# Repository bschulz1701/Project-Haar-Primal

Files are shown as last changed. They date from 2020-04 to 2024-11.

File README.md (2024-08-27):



# Project-Haar-Primal
A minimal temp/pressure/RH sensor designed for environmental monitoring. Built off the [Haar](https://github.com/NorthernWidget-Skunkworks/Project-Haar) system, developed by Bobby Schulz at Northern Widget 

# Repo Roadmap
#### [Documents](Documents/) 

General document and image storage for repo and README

#### [Hardware](Hardware/)

Current board files (Eagle), Bill of Materials (BoM), and other design documents

#### [Production](Production/)

Contains the various Gerber and pick and place files required to have the Printed Circuit Boards (PCBs) manufactured or populated 

#### [Software](Software/)

The software associated with the piece of hardware, this is usually diagnostic software used for verifying or investigating the hardware

#### [Mechanical](Mechanical/)

Mechanical design files and assembly documents

<!-- #### [Testing](Testing/)

Scripts and results from the testing process and development process. Contains more detailed information about documented issues among other testing. 
 -->

## Overview
* **Type:** Sensor
* **Interfaces:** I<sup>2</sup>C
* **Release Version:** v2.0 - 2022/03/17

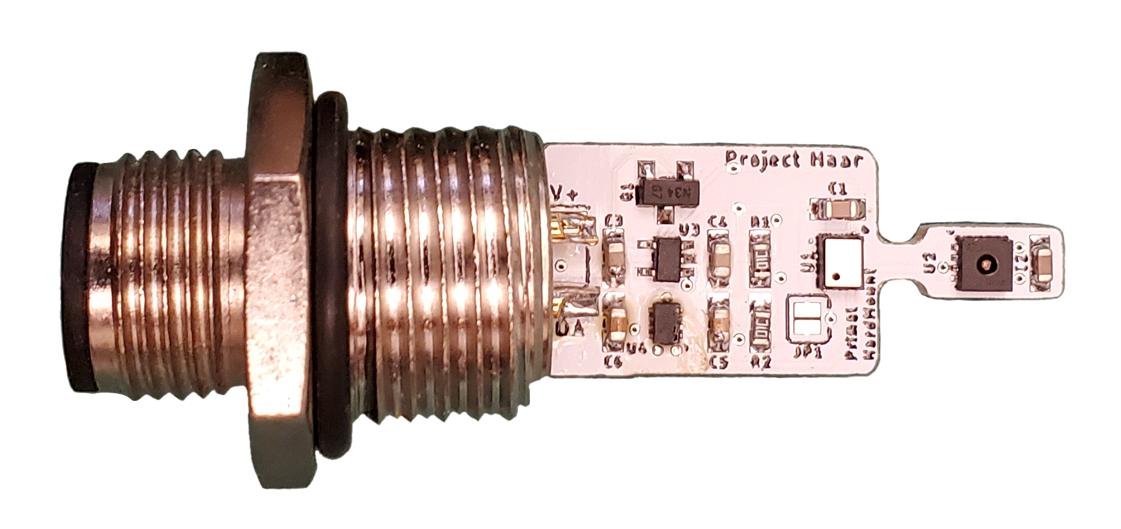
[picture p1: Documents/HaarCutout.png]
Haar Board Cutout


<!-- ![Haar v0.0 - Bottom](Documents/Images/Haar_0v0_Bottom_Cropped.jpg) -->

## Features
### On-Board
* Selectable Pullups
* Reverse Polarity Protection  

### Interface
* I<sup>2</sup>C
* M12 circular connector 

<picture>
  <source media="(prefers-color-scheme: dark)" srcset="Documents/Pinout_LIGHT.png">
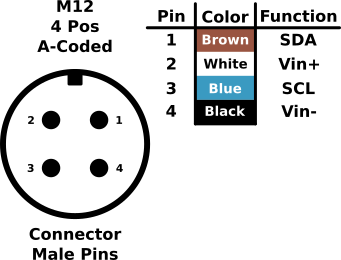
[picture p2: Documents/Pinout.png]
Haar Connector Pinout
  
</picture>

## Specifications
* **Voltage - Supply:** 3.3V
* **Voltage - Logic:** 3.3V
* **Input Current (Avg, 1s period): 30.95&mu;A @ 3.3V**
* **Input Current (Avg, 5s period): 107.43&mu;A @ 3.3V**
* **Input Current (Max): 0.45mA @ 3.3V**

#### Sensor
**Temperature** [^1]
* Range: -40 ~ 125°C 
* Accuracy: &plusmn; 0.2°C
* Repeatability: &plusmn; 0.04°C

**Pressure** [^2]
* Range: 300 ~ 1200 hPa  
* Accuracy: &plusmn; 1 hPa
* Repeatability: &plusmn; 0.06 hPa

**Humidity** [^1]
* Range: 0 ~ 100%
* Accuracy: &plusmn; 2%
* Repeatability: 0.08%

[^1]: [SHT31 Datasheet](https://sensirion.com/media/documents/213E6A3B/63A5A569/Datasheet_SHT3x_DIS.pdf)
[^2]: [DPS368 Datasheet](https://www.infineon.com/dgdl/Infineon-DPS368-DS-v01_00-EN.pdf?fileId=5546d46269e1c019016a0c45105d4b40)

## Version History

`v0.0` - Initial primal version with screw terminal

`v0.1` - Initial 'hard mount' version, using M12 connector

`v1.0` - Removed pullup select[^3], added logic level buffer and voltage reg on input

`v1.1` - Moved via away from connector pads to prevent bridging when soldering 

`v2.0` - Fixed issue with address select jumper[^3]

## Jumper Settings 

> [!IMPORTANT]
> Jumper settings valid for version `v2.0` and beyond[^3]

[^3]: See Errata

**Configuration Jumpers**
| Jumper | Purpose | Open | Closed | Default | 
| --- | --- | --- | --- | ----- |
| `JP1` | I<sup>2</sup>C Address Select | Base Address<sup>&dagger;</sup> | Alt Address<sup>&Dagger;</sup> | Open |

&dagger; SHT31 = `0x44`, DPS368 = `0x76`

&Dagger; SHT31 = `0x44`, DPS368 = `0x77`

## Known Issues/Errata

#### Solder Jumper Stencil

**Version Affected:** All

**Issue:** Depending on the thickness of the solder stencil used for populating the board, the solder jumpers may not bridge when desired. This is due to lack of stencil thickness specification and pad geometry.

**Workaround:** Make a note on the board assembly (if working with a board house) as to which jumpers should be connected (see jumper tables). Otherwise, if assembling manually, check the jumpers are connected, and bridge them using solder wire and a soldering iron if they have failed to jump where desired. 

#### Pullup Jumper

**Version Affected:** `v0.0`

**Issue:** Due to the resistor configuration with the solder jumper, if the jumper is left open, the resistors form a voltage divider which pulls down the I<sup>2</sup>C rails and causes a variety of bus failures.

**Workaround:** Leave jumper closed on device, this will pull the lines up to the 3.3V rail and prevent the issue 

**Resolution:** Fixed in version `v0.1` and beyond  

#### Address Jumper

**Version Affected:** `v0.1` to `v1.1`

**Issue:** `SDO` pin on DSP368 was erroniously left floating, meaning the DPS368 is continually fixed at the address of `0x76` and will not be effected by the address jumper status

**Workaround:** Leave jumper closed on device, this will hold the SHT31 at the default address as well and keep the address combination consistent 

**Resolution:** Fixed in version `v2.0` and beyond

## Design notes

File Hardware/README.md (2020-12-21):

# Hardware Overview - Project Hyena

## Files

<!-- * [Legacy](Legacy/) - File storage for older hardware versions   -->
* Haar_Primal.sch - Eagle Schematic
* Haar_Primal.brd - Eagle Board File
* [Haar_Primal_0v0_DimensionalDrawing.pdf](Haar_Primal_0v0_DimensionalDrawing.png) - Mechanical Drawing
<!-- * [PrimaryLogger_BoM.csv](PrimaryLogger_BoM.csv) - BoM (For reference only, see [Production](../Production) for production ready BoM) -->
<!-- * [PrimaryLogger.pdf](PrimaryLogger_0v2.pdf) - PDF of Schematic  -->

## I2C Addresses 

| Device | Address | 
| --- | --- |
| DPS368 | 0x77 | 
| SHT30 | 0x44 |

<!-- ## Pinout

| Particle Pin | Hyena Pin Name | Control | Function | 
| --- | --- | --- | --- |
| 8 | `3V3_EXT_EN` | Output | Enables the external 3.3v rail (active high, nominally low) | 
| 7 | `WD_HOLD` | Output | Controls the hardware watchdog timer, pulse high to "feed" timer |
| 6 | `GPIO1D` | IO | General digital IO pin for external sensors (J1 Connector) | 
| 5 | `GPIO2D` | IO | General digital IO pin for external sensors (J2 Connector) | 
| 4 | `GPIO3D` | IO | General digital IO pin for external sensors (J3 Connector) | 
| 3 | `RTC_INT` | Input | Interrupt line from RTC, natively high active low (open drain), triggers on falling edge |
| 2 | `SDA_CTRL` | Output | Used to turn internal I2C on or off (active high, I2C_OB on, natively low) |
| 1 | `SCL` | Output | I2C clock line |
| 0 | `SDA` | IO | I2C Data line |
| 9 | `3V3_SD_EN` | Output | Enable line for SD card 3.3v supply (active high, natively low) |
| 10 | `IO_EXP_INT` | Input | Global interrupt from the IO expander (functionality configurable via software) |
| 11 | `MISO` | Input | MasterInSlaveOut, part of SPI bus |
| 12 | `MOSI` | Output | MasterOutSlaveIn, part of SPI bus | 
| 13 | `SCK` | Output | SerialClocK, part of SPI bus | 
| 14 | `SD_CS` | Output | SD chip select line, active low |
| 15/ADC4 | `TIP` | IO | Designed as tipping bucket rain gauge input, connected to J6, pulled high by default |
| 16/ADC3 | `GPIOXA` | IO | Intended as analog input for potentiometric input (J5) |
| 17/ADC2 | `GPIO1A` | IO | General digital/analog IO pin for external sensors (J1 Connector) |
| 18/ADC1 | `GPIO2A` | IO | General digital/analog IO pin for external sensors (J2 Connector) |
| 19/ADC0 | `GPIO3A` | IO | General digital/analog IO pin for external sensors (J3 Connector) |

| IO Expander Pin | Hyena Pin Name | Control | Function |
| --- | --- | --- | --- |
| 0 | `3V3_EXT_FAULT` | Input | Monitor pin for external 3v3 rail, if over current trip, pin is pulled low, natively high |
| 1 | `3V3_SD_FAULT` | Input | Monitor pin for SD card 3v3 rail, if over current trip, pin is pulled low, natively high |
| 2 | `SD_CD` | Input | Card detect pin for SD card, natively high, pulled low to indicate physical presence of SD card | 
| 3 | `I2C_EXT_EN` | Output | Control line for external I2C buffer, natively high (on), can be pulled low to turn off the external I2C bus | 
| 4 | `PAR_INT` | Input | Event interrupt line from TCS3400 light sensor (used for PAR measurement), active low interrupt |

## Hardware Testing:
See Testing sub folder -->

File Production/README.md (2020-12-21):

# Production
This folder contains files used to have the hardware manufactured 

## Files

#### Version v0.0 - Release Version

* [Geber](Haar_Primal_2020-03-13_x274.zip)
<!-- * [Top Mount](PrimaryLogger_v2.mnt) -->
* [BoM](Haar_Primal_0v0_BoM.csv)

### File Conventions 
* `HardwareName.mnb` - These are mount files (pick and place) for the bottom of the board
* `HardwareName.mnt` - These are mount files (pick and place) for the top of the board
* `HardwareName_YYYY-MM-DD_x274.zip` - These are Gerber (PCB) files from a given date in x274 format, which is accepted by most board houses

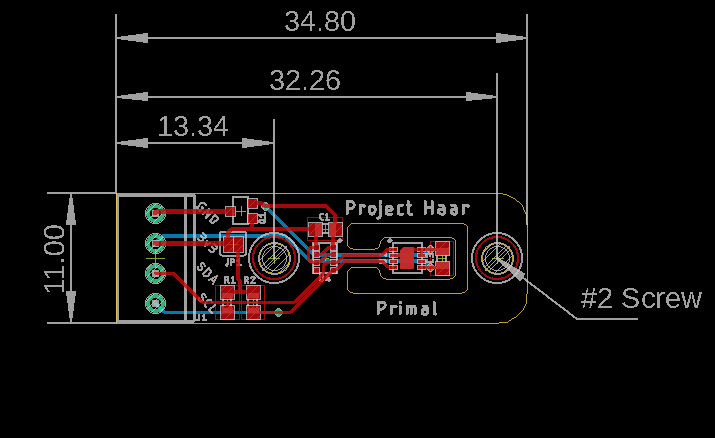
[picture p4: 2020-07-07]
Documents/Haar_Primal_0v0_DimentionalDrawing.png

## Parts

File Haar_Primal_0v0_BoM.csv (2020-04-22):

Qty | Value | Device | Package | Parts | Description | DIGIKEY | DISP | MF | MPN | PROD_ID | VALUE | VALUE_PART
2 |  | MOUNTING_HOLE2_NP | 2_56 | H1, H2 | Genaric Mechanical Mounting Hole
2 | 0.1uF | C-EU0.1UFC0603 | C0603 | C1, C3 | CAPACITOR, European symbol | 490-6051-1-ND |  | Murata | GCM188R71E104KA57D
2 | 10k | R-EU_10KR0603 | R0603 | R1, R2 | RESISTOR, European symbol | 311-10.0KHRCT-ND |  | Yageo | RC0603FR-0710KL |  |  | 10k
1 | 2N7002 | MOSFET-NCH-2N7002PW | SOT323 | Q1 | N-channel MOSFETs | 2N7002W-FDICT-ND |  | Diodes Incorporated | 2N7002W-7-F | TRANS-11151 | 2N7002
1 | CONN_42.54_SCREW | CONN_42.54_SCREW | 1X04_SCREW | J1 | Genaric 4 terminal header | ED10563-ND |  | On Shore | OSTVN04A150
1 | DPS368 | DPS368 | PG-VLGA-8 | U4 | DPS368 - Digital Pressure Sensor | DPS368XTSA1CT-ND | DPS368 | Infineon | DPS368XTSA1
1 | JUMPER-SMT_2_NC_PASTE_SILK | JUMPER-SMT_2_NC_PASTE_SILK | SMT-JUMPER_2_NC_PASTE_SILK | JP1 | Normally closed solder jumper
1 | SHT30DFN | SHT30DFN | DFN_8_2.5X2.5 | U1 | SHT3x - Digital Humidity and Temperature Sensor | 1649-1065-1-ND | SHT30 | Sensirion | SHT30-DIS-F2.5KS

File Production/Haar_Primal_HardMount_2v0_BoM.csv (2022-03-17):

Qty | Value | Device | Package | Parts | Description | DIGIKEY | DISP | MF | MPN | VALUE | VALUE_PART
4 | 0.1uF | C-EU0.1UFC0603 | C0603 | C1, C2, C5, C6 | CAPACITOR, European symbol | 490-6051-1-ND |  | Murata | GCM188R71E104KA57D
2 | 10k | R-EU_100KR0603 | R0603 | R1, R2 | RESISTOR, European symbol | 311-100KHRCT-ND |  | Yageo | RC0603FR-07100KL |  | 100k
2 | 1uF | C-EU1UFC0603 | C0603 | C3, C4 | CAPACITOR, European symbol | 587-1251-1-ND |  | Yaiyo Yuden | EMK107BJ105KA-T
1 | CONN_I2C_SENSOR_EDGE_MOUNT | CONN_I2C_SENSOR_EDGE_MOUNT | SOLDERCUP_CONN_QUAD | J1 | GEMS Connector for I2C Devices - Sensor Side | A97650-ND |  | TE Connectivity | 1838893-2
1 | DMG3404 | MOSFET-NCH-DMG3404L | SOT23-3 | Q1 | N-channel MOSFETs | DMG3404L-7DICT-ND |  | Diodes Incorporated | DMG3404L-7 | DMG3404
1 | DPS368 | DPS368 | PG-VLGA-8 | U1 | DPS368 - Digital Pressure Sensor | DPS368XTSA1CT-ND | DPS368 | Infineon | DPS368XTSA1
1 | JUMPER-SMT_2_NO_SILK | JUMPER-SMT_2_NO_SILK | SMT-JUMPER_2_NO_SILK | JP1 | Normally open jumper | DNP |  | N/A | N/A
1 | SHT31DFN | SHT31DFN | DFN_8_2.5X2.5 | U2 | SHT3x - Digital Humidity and Temperature Sensor | 1649-1066-1-ND | SHT31 | Sensirion | SHT31-DIS-F2.5KS
1 | TPS79733 | TPS79733 | DCK_R-PDSO-G5 | U3 | TPS797* - Ultra Low Power Low Dropout Linear Regulator | 296-11990-1-ND | TPS79733 | TI | TPS79733DCKR
1 | TXS0102DQM | TXS0102DQM | DQM_R-PX2SON-N8 | U4 | TXS0102 - 2 Channel Bidirectional Voltage Level Translator | 296-28435-1-ND |  | TI | TXS0102DQMR

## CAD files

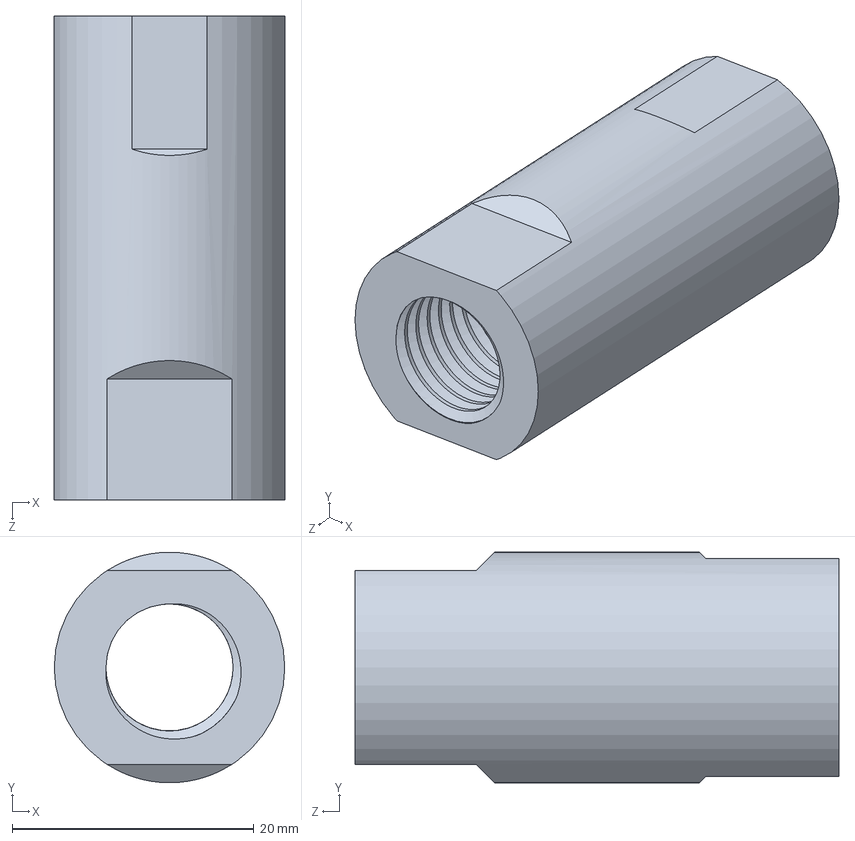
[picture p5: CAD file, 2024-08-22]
Mechanical/ClosedBody/ClosedBody.SLDPRT
19.1 x 19.1 x 40.0 mm

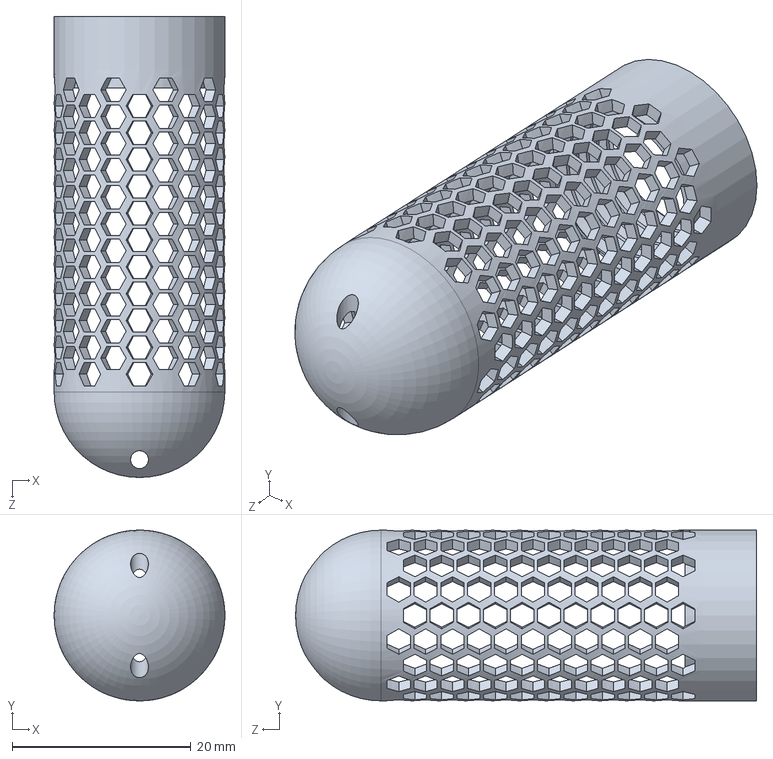
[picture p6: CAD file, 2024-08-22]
Mechanical/OpenBody/OpenBody.SLDPRT
19.1 x 19.1 x 51.5 mm

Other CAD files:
Mechanical/ClosedBody/ClosedBody.STL
Mechanical/OpenBody/OpenBody.STL

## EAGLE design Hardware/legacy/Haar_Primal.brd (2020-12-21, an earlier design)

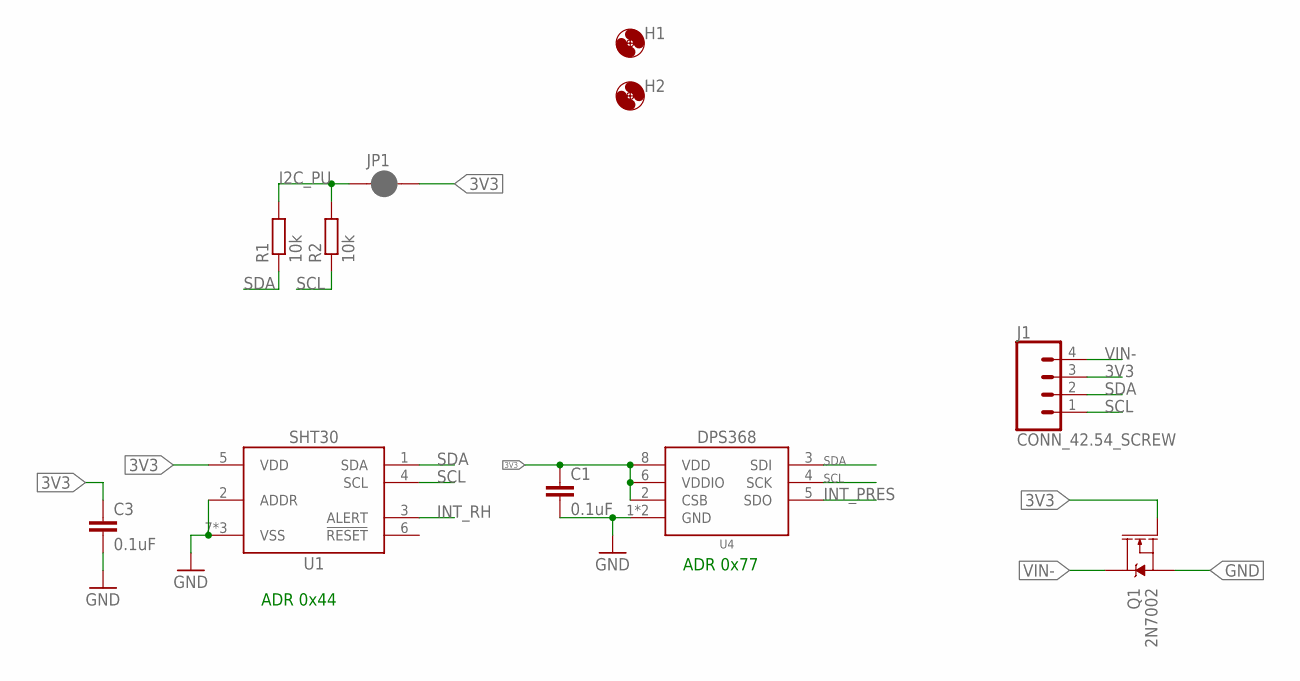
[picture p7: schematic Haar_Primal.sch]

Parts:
C1, C3: 0.1uF; C0603
H1, H2: MOUNTING_HOLE2_NP; 2_56
J1: CONN_42.54_SCREW; 1X04_SCREW
JP1: JUMPER-SMT_2_NC_PASTE_SILK; SMT-JUMPER_2_NC_PASTE_SILK
Q1: 2N7002; SOT323
R1, R2: 10k; R0603
U1: SHT30DFN; DFN_8_2.5X2.5
U4: DPS368; PG-VLGA-8

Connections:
3V3: C1.1, C3.1, J1.3, JP1.2, Q1.1 (G), U1.5 (VDD), U4.2 (CSB), U4.6 (VDDIO), U4.8 (VDD)
GND: C1.2, C3.2, Q1.2 (S), U1.2 (ADDR), U1.7 (VSS), U1.8 (VSS), U1.EP (VSS), U4.1 (GND), U4.7 (GND)
I2C_PU: JP1.1, R1.2, R2.2
INT_PRES: U4.5 (SDO)
INT_RH: U1.3 (ALERT)
SCL: J1.1, R2.1, U1.4 (SCL), U4.4 (SCK)
SDA: J1.2, R1.1, U1.1 (SDA), U4.3 (SDI)
VIN-: J1.4, Q1.3 (D)

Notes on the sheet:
ADR 0x77
ADR 0x44

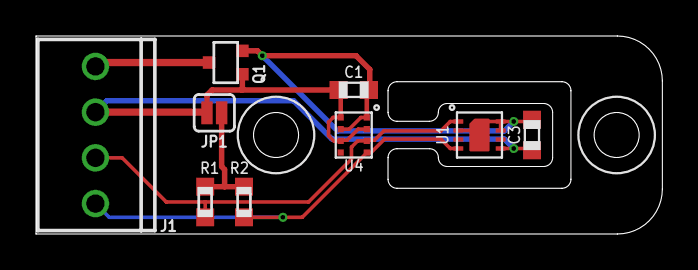
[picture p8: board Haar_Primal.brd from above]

Board: 2 copper layers, 34.8 x 11.0 mm, 11 parts (0 on the bottom side), 6 nets.

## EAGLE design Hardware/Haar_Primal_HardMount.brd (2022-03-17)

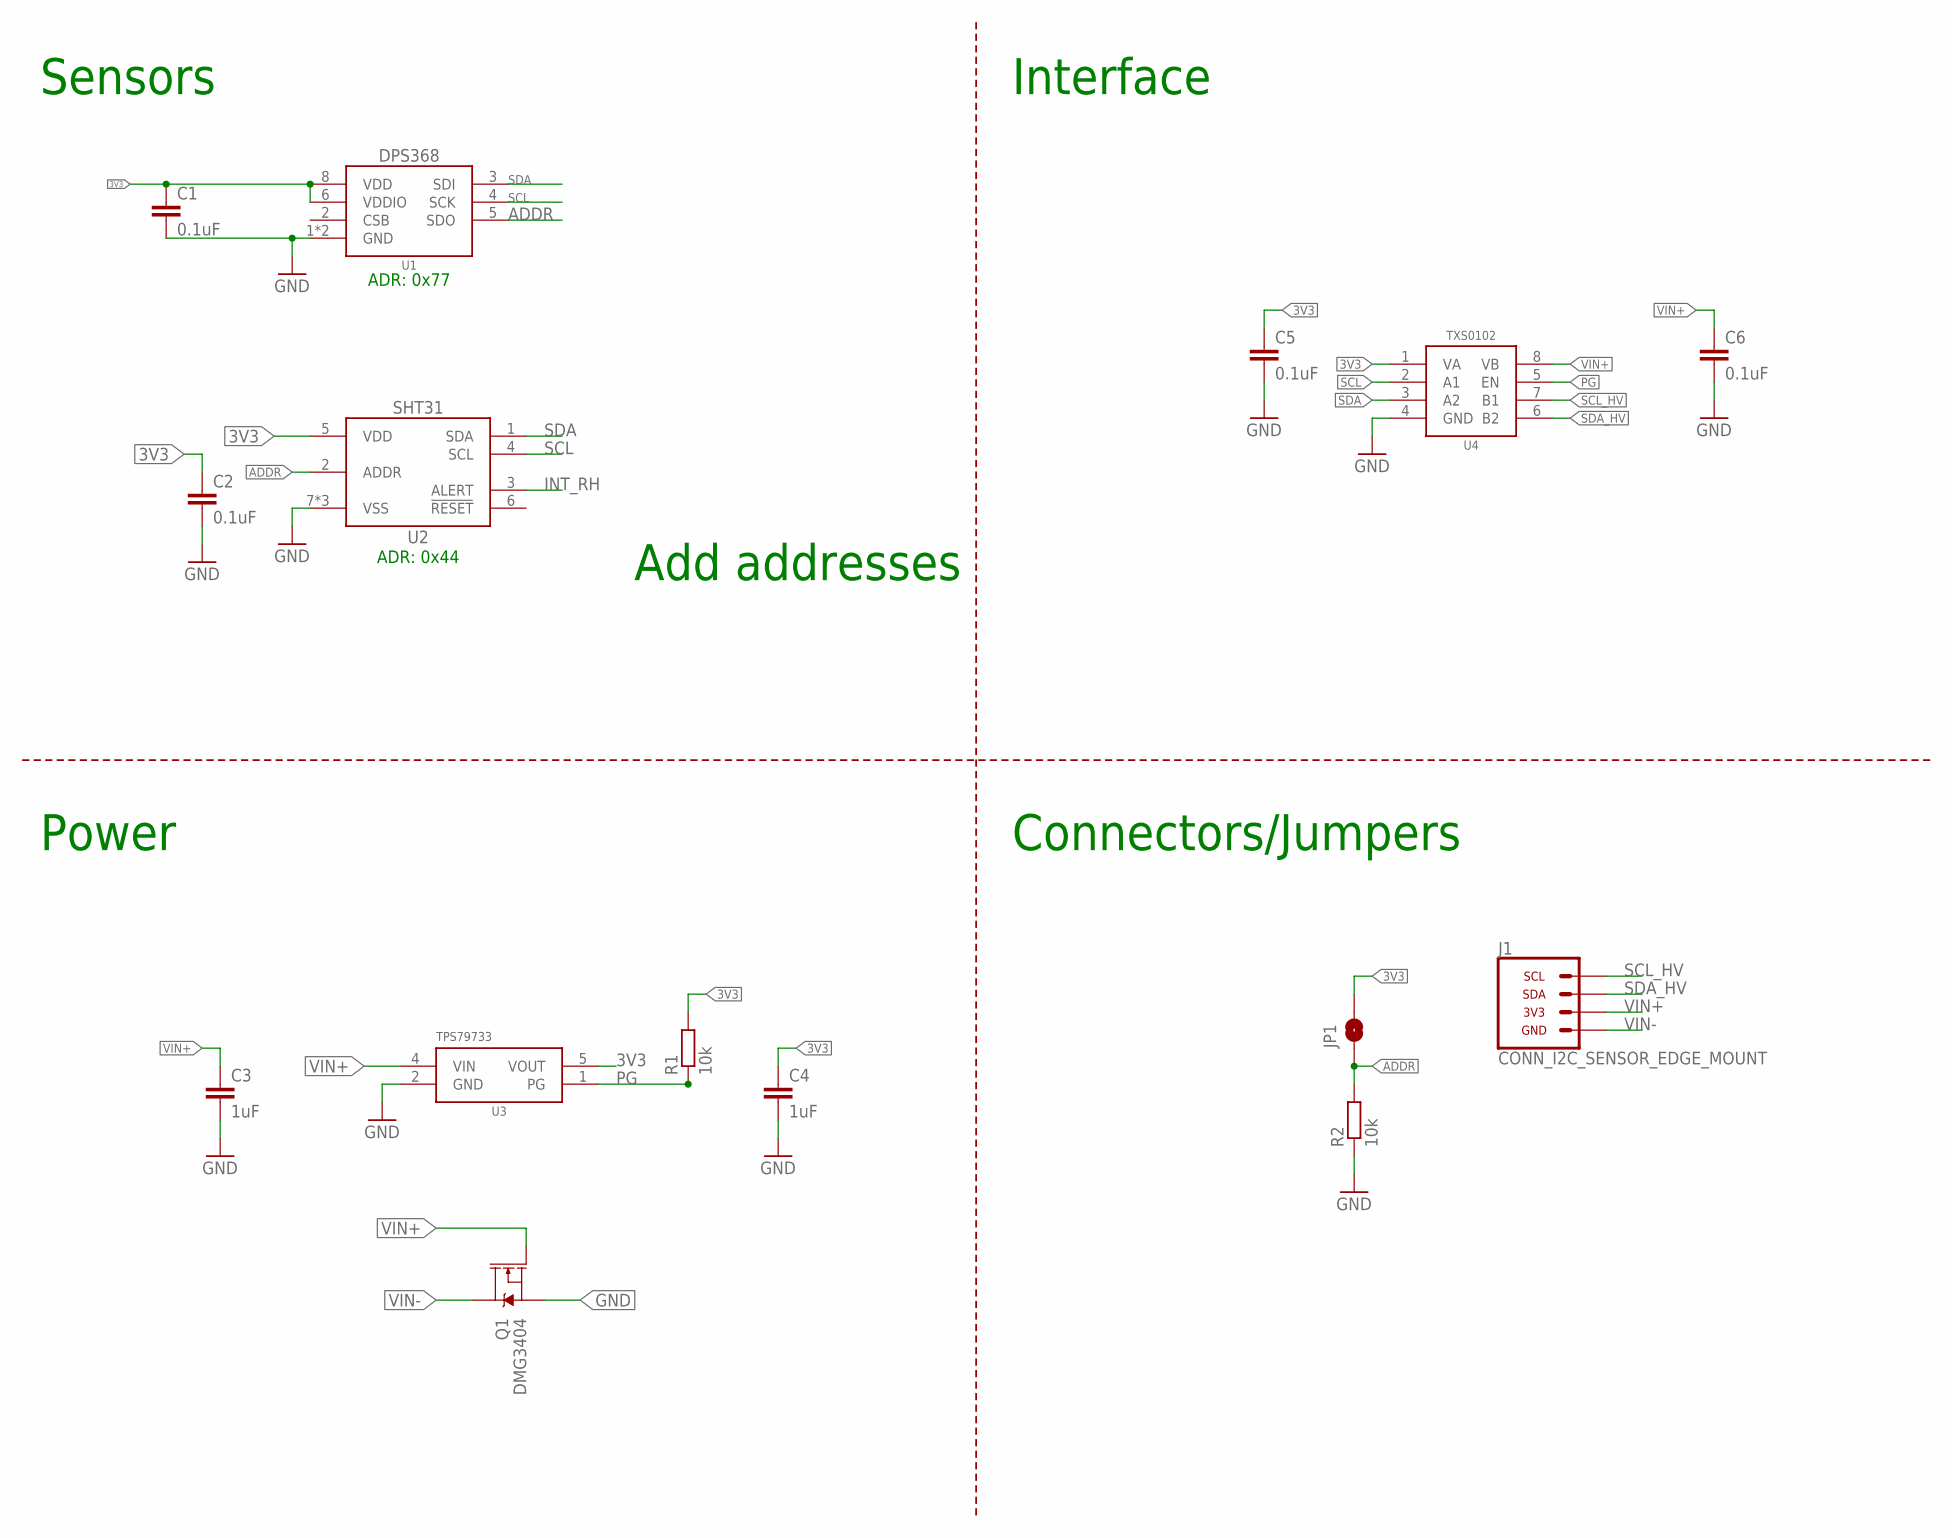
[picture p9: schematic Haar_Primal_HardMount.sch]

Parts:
C1, C2, C5, C6: 0.1uF; C0603
C3, C4: 1uF; C0603
J1: CONN_I2C_SENSOR_EDGE_MOUNT; SOLDERCUP_CONN_QUAD
JP1: JUMPER-SMT_2_NO_SILK; SMT-JUMPER_2_NO_SILK
Q1: DMG3404; SOT23-3
R1, R2: 10k; R0603
U1: DPS368; PG-VLGA-8
U2: SHT31DFN; DFN_8_2.5X2.5
U3: TPS79733; DCK_R-PDSO-G5
U4: TXS0102DQM; DQM_R-PX2SON-N8

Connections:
3V3: C1.1, C2.1, C4.1, C5.1, JP1.2, R1.2, U1.6 (VDDIO), U1.8 (VDD), U2.5 (VDD), U3.5 (VOUT), U4.1 (VA)
ADDR: JP1.1, R2.2, U1.5 (SDO), U2.2 (ADDR)
GND: C1.2, C2.2, C3.2, C4.2, C5.2, C6.2, Q1.2 (S), R2.1, U1.1 (GND), U1.7 (GND), U2.7 (VSS), U2.8 (VSS), U2.EP (VSS), U3.2 (GND), U4.4 (GND)
INT_RH: U2.3 (ALERT)
PG: R1.1, U3.1 (PG), U4.5 (EN)
SCL: U1.4 (SCK), U2.4 (SCL), U4.2 (A1)
SCL_HV: J1.3 (SCL), U4.7 (B1)
SDA: U1.3 (SDI), U2.1 (SDA), U4.3 (A2)
SDA_HV: J1.1 (SDA), U4.6 (B2)
VIN+: C3.1, C6.1, J1.2 (3V3), Q1.1 (G), U3.4 (VIN), U4.8 (VB)
VIN-: J1.4 (GND), Q1.3 (D)

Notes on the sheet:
Sensors
Interface
Power
Connectors/Jumpers
Add addresses
ADR: 0x44
ADR: 0x77

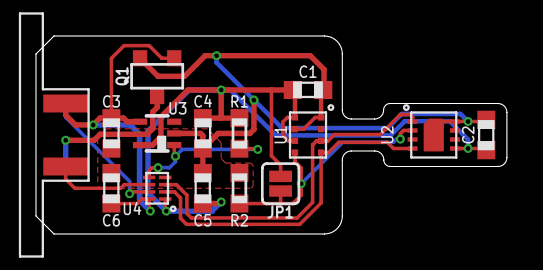
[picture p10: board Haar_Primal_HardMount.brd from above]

Board: 2 copper layers, 26.2 x 11.0 mm, 15 parts (0 on the bottom side), 10 nets.

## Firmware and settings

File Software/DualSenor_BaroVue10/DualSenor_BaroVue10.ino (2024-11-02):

#include <Dps368.h>
#include <Arduino.h>
#include <Wire.h>
#include "Adafruit_SHT31.h"

const uint8_t TX = 1;
const uint8_t RX = 0;
const uint8_t FOut = 12;
const uint8_t Dir = 11;

#define MARKING_PERIOD 9 //>8.33ms for standard marking period
const unsigned long TimeoutStandard = 380; //Standard timeout period for most commands is 380ms 

char ReadArray[25] = {0};

const unsigned long period = 1000; //Wait 1 second between logs

// Dps368 Opject
Dps368 Pres1 = Dps368();
Dps368 Pres2 = Dps368();

bool enableHeater = false;
uint8_t loopCnt = 0;

Adafruit_SHT31 RH1 = Adafruit_SHT31();
Adafruit_SHT31 RH2 = Adafruit_SHT31();

void setup() {
	pinMode(TX, OUTPUT);
	pinMode(FOut, OUTPUT);
	pinMode(Dir, OUTPUT);

	digitalWrite(Dir, HIGH); //Set to transmit 
	Serial1.begin(1200, SERIAL_7E1);
	Serial.begin(115200);
	while(!Serial) { //Wait until serial interface is available 
		;
	} 
	Serial.println("BaroVue10");
	Serial.println("Time[s]\tPres[mBar]\tTemp[°C]\tPres1[mBar]\tTemp1A[°C]\tTemp1B[°C]\tRH1[%]\tPres2[mBar]\tTemp2A[°C]\tTemp2B[°C]\tRH2[%]");

	Pres2.begin(Wire, 0x76);
	//Use the commented line below instead of the one above to use the default I2C address.
	//if you are using the Pressure 3 click Board, you need 0x76
	Pres1.begin(Wire);
	RH1.begin(0x45);
	RH2.begin(0x44);

	// unsigned long startTime = millis();
	
}

void loop() {

	float temperature1;
	float pressure1;
	float temperature2;
	float pressure2;
	uint8_t oversampling = 7;
	int16_t ret;
	unsigned long readStart = millis();
	//lets the Dps368 perform a Single temperature measurement with the last (or standard) configuration
	//The result will be written to the paramerter temperature
	//ret = Dps368PressureSensor.measureTempOnce(temperature);
	//the commented line below does exactly the same as the one above, but you can also config the precision
	//oversampling can be a value from 0 to 7
	//the Dps 368 will perform 2^oversampling internal temperature measurements and combine them to one result with higher precision
	//measurements with higher precision take more time, consult datasheet for more information
	ret = Pres1.measureTempOnce(temperature1, oversampling);
	//Pressure measurement behaves like temperature measurement
	//ret = Dps368PressureSensor.measurePressureOnce(pressure);
	ret = Pres1.measurePressureOnce(pressure1, oversampling);

	ret = Pres2.measureTempOnce(temperature2, oversampling);
	//Pressure measurement behaves like temperature measurement
	//ret = Dps368PressureSensor.measurePressureOnce(pressure);
	ret = Pres2.measurePressureOnce(pressure2, oversampling);
	float t1 = RH1.readTemperature();
	float h1 = RH1.readHumidity();
	float t2 = RH2.readTemperature();
	float h2 = RH2.readHumidity();
	

	SendCommand("0M!");
	delay(1000);
	String data = SendCommand("0D0!");
	data = data.substring(4, data.length()); //Trim address val
	// Serial.println(data); //DEBUG!
	float temp, rh;
	// Serial.println(data.substring(0, NextIndexOfSep(data)));
	temp = DataToFloat(data.substring(0, NextIndexOfSep(data))); //Grab first float from data
	data = data.substring(NextIndexOfSep(data) + 1, data.length()); //Trim first chunk off of data
	// Serial.println(data.substring(0, NextIndexOfSep(data)));
	rh = DataToFloat(data.substring(0, NextIndexOfSep(data))); //Grab other float from data
	static unsigned long printTime = millis();
	if(floor(millis()/1000.0) != millis()/1000.0) { //If data out of sync, perform sync
		while(floor(millis()/1000.0) != millis()/1000.0); //Wait for seconds to match
	}
	while((millis() - printTime) < 1000.0); //Wait until time is up
	printTime = millis();
	Serial.print(millis()/1000.0);
	Serial.print('\t');
	Serial.print(temp);
	Serial.print('\t');
	Serial.print(rh);
	Serial.print("\t");

	Serial.print(pressure1/100.0);
	Serial.print("\t");
	Serial.print(temperature1);
	Serial.print("\t");
	Serial.print(t1);
	Serial.print("\t");
	Serial.print(h1);
	Serial.print("\t");

	Serial.print(pressure2/100.0);
	Serial.print("\t");
	Serial.print(temperature2);
	Serial.print("\t");
	Serial.print(t2);
	Serial.print("\t");
	Serial.println(h2);
}

uint8_t IndexOfSep(String val) //Find the first index of the value seperator 
{
	uint8_t pos = val.indexOf('+');
	uint8_t neg = val.indexOf('-');
	if(pos == -1 || neg == -1) return max(pos, neg); //If one of them is not found, return the other one
	else return min(pos, neg); //If both are valid, then return the first

}

uint8_t NextIndexOfSep(String val) //Find the NEXT index of the value seperator 
{
	uint8_t pos = val.indexOf('+');
	uint8_t neg = val.indexOf('-');
	if(pos == -1 || neg == -1) return max(pos, neg); //If one of them is not found, return the other one
	else if (pos == 0 || neg == 0) return IndexOfSep(val.substring(1, val.length())); //If the first value is a seperator, call normal IndexOfSep, but give is 1:n as an inpus
	else return max(pos, neg); //If both are valid, AND the first element is not a seperator, then return the LATER one
}

float DataToFloat(String val)
{
	char sign = val.charAt(0); //Grab first char to test for signage
	val = val.substring(1, val.length()); //Trim sign char
	float data = val.toFloat();
	data = (sign == '+') ? data : -1.0*data; //Adjust sign of data if needed
	return data;
}

char GetAddress()
{
	SendBreak(); //Send break to start message
	Mark(MARKING_PERIOD); //Mark for standard period before command
	Serial1.begin(1200, SERIAL_7E1);
	Serial1.print("0I!");
	Serial1.flush(); //Make sure data is transmitted before releasing the bus
	delay(1);
	ReleaseBus(); //Switch bus to recieve 
	// char Var = Serial.re

	unsigned long LocalTime = millis();
	// bool GotData = false;
	while(Serial1.available() < 3 && (millis() - LocalTime) <  TimeoutStandard);
	String Val = Serial1.readStringUntil('\r');
	Serial.println(Val);
	return 0; //DEBUG!
}

void SendBreak()
{
	pinMode(Dir, OUTPUT); //Make sure direction is set to output
	pinMode(FOut, OUTPUT); //Make sure the force out pin is in output mode
	digitalWrite(Dir, HIGH); //Set direction to output
	digitalWrite(FOut, LOW); //Set low to force output high
	delay(13); //Wait for bus to acnowledge action
	digitalWrite(FOut, HIGH); //Stop forcing output
}

void Mark(unsigned long Period)
{
	pinMode(Dir, OUTPUT); //Make sure direction control pin is set as an output
	pinMode(TX, OUTPUT); //Make sure transmit pin is set as output
	digitalWrite(Dir, HIGH); //Set direction to output
	digitalWrite(TX, 1); //Begin marking condition
	delay(Period); //Wait for a given marking period
	digitalWrite(TX, 0); //Stop marking  
}

void Space(unsigned long Period)
{
	pinMode(Dir, OUTPUT); //Make sure direction control pin is set as an output
	pinMode(TX, OUTPUT); //Make sure transmit pin is set as output
	digitalWrite(Dir, HIGH); //Set direction to output
	digitalWrite(TX, 0); //Begin spacing condition
	delay(Period); //Wait for a given marking period
	digitalWrite(TX, 1); //Stop spacing
}

// void SendCommand()

void ReleaseBus() 
{
	pinMode(Dir, OUTPUT); //Make sure direction pin is set as an output
	digitalWrite(Dir, LOW); //Set direction to input
}

String SendCommand(String Command) 
{
	SendBreak(); //Send break to start message
	Mark(MARKING_PERIOD); //Mark for standard period before command
	Serial1.begin(1200, SERIAL_7E1);
	Serial1.print(Command);
	Serial1.flush(); //Make sure data is transmitted before releasing the bus
	delay(1);
	ReleaseBus(); //Switch bus to recieve 
	// char Var = Serial.re

	unsigned long LocalTime = millis();
	char Data[100] = {0}; //Make data array for storage FIX! Change length to not be arbitrary
	bool GotData = false; //Used to keep track of terminating character has been recieved 
	int Pos = 0; //Keep track of position in data array
	while(!GotData && (millis() - LocalTime) <  TimeoutStandard) {
		if(Serial1.available() > 0) {
			Data[Pos] = Serial1.read(); //If byte is available, read it in
			Pos++; //Increment position
		}
		if(Data[Pos] == '\n') GotData = true; //Set flag if end character is read in
	}
	String Val = String(Data); //Convert to String
	Val.trim(); //Get rid of any trailing characters 
	// while(Serial1.available() < 3 && (millis() - LocalTime) <  TimeoutStandard);
	// String Val = Serial1.readStringUntil('\r');
	// Serial.println(Val);
	return Val; 
}

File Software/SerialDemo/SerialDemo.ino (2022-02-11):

#include <Dps368.h>
#include <Adafruit_SHT31.h>

Dps368 pressureSense = Dps368(); //Instantiate DPS368 Pressure sensor
Adafruit_SHT31 rhSense = Adafruit_SHT31(); //Instantiate the SHT31 RH/Temp sensor

const uint8_t dps368_oversampling = 7; //Define the oversampling amount for the DPS368 sensor
unsigned long period = 5000; //Number of ms to wait between sensor readings

void setup() {
	Serial.begin(115200); //Begin serial conunication at high speed 
	// uint8_t error_dps368 = pressureSense.begin(Wire); //Initialize DPS368 sensor
	uint8_t error_dps368 = 0; //DEBUG! FIX! Change library to return stuff properly
	pressureSense.begin(Wire); //Initialize DPS368 sensor //DEBUG! FIX! Change library to return stuff properly
	uint8_t error_sht31 = rhSense.begin(0x44); //Initialize SHT31 sensor
	
	Serial.println("Haar Status:"); //Print resulting sensor status 
	Serial.print("\tDPS368: "); 
	if(error_dps368 == 1) Serial.print("PASS\n"); //Print error grabbed from sensor
	else Serial.print("FAIL!\n"); //Fail if result is not 0
	Serial.print("\tSHT31: ");
	if(error_sht31 == 1) Serial.print("PASS\n"); //Print error grabbed from sensor
	else Serial.print("FAIL!\n"); //Fail if result is 0
}

void loop() {

	float temp_dps368; //Storage for temp measurement from DPS368 
  	float pressure; //Storage for pressure measurment from DPS368
  	

	int16_t error1 = pressureSense.measureTempOnce(temp_dps368, dps368_oversampling); //Grab new temp values [°C]
	int16_t error2 = pressureSense.measurePressureOnce(pressure, dps368_oversampling); //Grab new pressure values [Pa]
	pressure = pressure/100.0f; //Convert from Pa to mBar, because Pa is a stupid unit, and hPa is more stupid. 

	float humidity = rhSense.readHumidity(); //Grab new humidity values [%]
	float temp_sht31 = rhSense.readTemperature(); //Grab new temp values [°C]

	Serial.print("Temp (SHT31): "); Serial.print(temp_sht31, 4); Serial.print(" °C\t"); //Print temp to 4 decimal places
	Serial.print("Temp (DPS368): "); Serial.print(temp_dps368, 2); Serial.print(" °C\t"); //Print temp to 2 decimal places
	Serial.print("Pressure: "); Serial.print(pressure, 2); Serial.print(" mBar\t"); //Print pressure to 2 decimal places
	Serial.print("Humidity: "); Serial.print(humidity, 2); Serial.print(" %\n"); //Print humidity to 2 decimal places
	delay(period); //Wait a specified period before the next sensor reading
}

String printError(uint8_t val) //Print out error result 
{
	if(val != 0) return "FAIL!"; //Return fail in all but 0 case
	else return "PASS"; //Return pass if result == 0
}

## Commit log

2020-03-19 Updating from local development
    Create seperate repo and update from local development, v0.0 already constructed and tested
    [Haar_Primal.brd, Haar_Primal.sch]
2020-04-22 Generated BoM
    [Haar_Primal_0v0_BoM.csv]
2020-07-07 Added dimentional drawing
    [Haar_Primal.brd]
2020-12-21 Updated documentation to match standard
    Updated docs and readmes, need to add photos of board
    [Haar_Primal.brd, Haar_Primal.sch, Haar_Primal_0v0_BoM.csv]
2021-04-07 Hard mount v0.1 addition
    Added hard mount version and made v0.1 updates to design
    [Haar_Primal_HardMount.brd, Haar_Primal_HardMount.sch]
2021-04-09 Updated Hard Mount - Variable address jumper
    Added jumper to Hard Mount to allow for a variable address configuration
    [Haar_Primal_HardMount.brd, Haar_Primal_HardMount.sch]
2021-04-14 Generated gerber for v0.1 Hard Mount
2022-02-11 Added Haar Primal
    [Haar_Primal.brd, Haar_Primal.sch, Haar_Primal_0v0_BoM.csv]
2022-02-11 Added pick and place and quote files for v0.1 Hard Mount
    [Haar_Primal_HardMount_0v1_BoM.csv]
2022-02-11 Added v1.0 Hard Mount and basic serial demo
2022-02-11 Hard Mount v1.1 Update
    [Haar_Primal_HardMount.brd, Haar_Primal_HardMount.sch]
2022-02-11 v2.0 Updates - Generated Gerbers
    Fixed ADDR pinout to DPS368
    [Haar_Primal_HardMount.brd, Haar_Primal_HardMount.sch]
2022-03-17 Updated passive values for v2.0
    Updated some passives and added BoM and mnt
    [Haar_Primal_HardMount.brd, Haar_Primal_HardMount.sch, Haar_Primal_HardMount_2v0_BoM.csv]
2022-12-19 Cleaned up folders
    [Haar_Primal.brd, Haar_Primal.sch, Haar_Primal_0v0_BoM.csv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]
2024-08-22 Added documentation to README and mechanical files
    Added significant documentation to the README
    - Pinout diagram
    - Updated photo
    - Updated specs
    - Updated jumper info
    - Resolved errata
    Added mechanical files for closed and open housing
    [ClosedBody.SLDPRT, ClosedBody.STL, OpenBody.SLDPRT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]

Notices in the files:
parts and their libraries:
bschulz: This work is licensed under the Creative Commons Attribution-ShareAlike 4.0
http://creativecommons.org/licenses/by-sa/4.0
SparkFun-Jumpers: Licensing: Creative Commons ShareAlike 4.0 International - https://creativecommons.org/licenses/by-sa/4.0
